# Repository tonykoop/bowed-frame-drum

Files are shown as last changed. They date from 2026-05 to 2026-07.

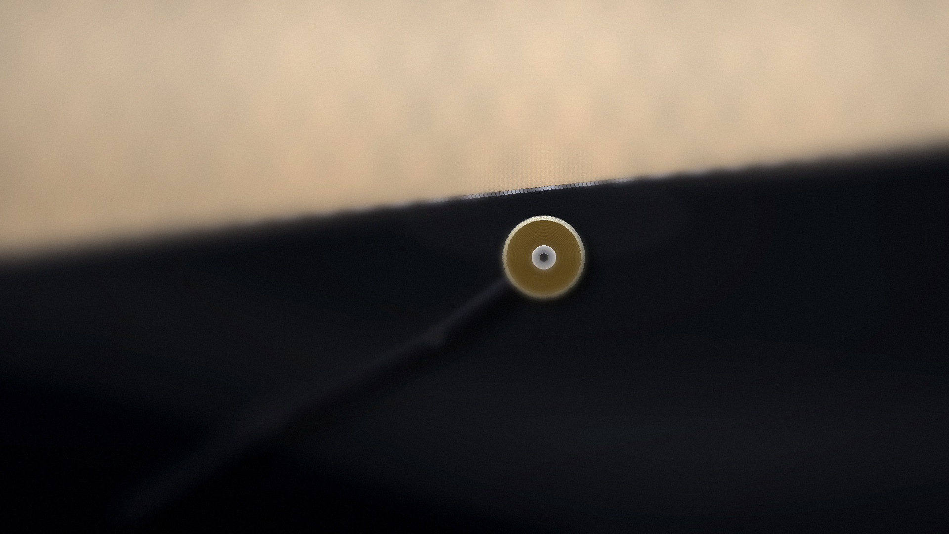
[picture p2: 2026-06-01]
images/macro/rosined-wheel-arm.png

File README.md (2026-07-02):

<!-- SPDX-License-Identifier: CC-BY-4.0 -->
# Bowed Frame Drum

Status: L2 V5 build-packet candidate - organized for prototype/shop review,
but not L3/build-ready. CAD/DXF outputs are planned placeholders, acoustic
targets are unmeasured predictions, and fabrication authority remains
`pending_measurement` until physical validation and reviewed CAD/DXF exist.

**Family**: Membranophone — frame drum  
**Archetype**: Irish bodhran  
**Target tuning**: C3 fundamental (130.8 Hz), A3 first overtone (219 Hz)  
**Ergonomic envelope**: 450 mm OD × 90 mm deep, ~900 g

## Design Thesis

A bodhran-scale frame drum with a rolled 1.0 mm cold-rolled steel cylinder frame instead of
the traditional laminated wood hoop. Inside the frame, a flat CR-steel tone bar (400 × 25 × 1 mm)
is suspended on two neoprene grommets and vibrates sympathetically when the head is struck,
adding an overtone shimmer near C4 (257 Hz). An optional rosined brass wheel on a cantilevered
arm produces a sustained bowed drone in the 80–400 Hz range — transforming a percussion instrument
into a hybrid membranophone/bowed instrument.

## Quick Stats

| | |
|---|---|
| Frame OD | 450 mm |
| Frame depth | 90 mm |
| Frame material | 1.0 mm CR steel, ASTM A1008, butt-TIG seam |
| Head | Remo Skyndeep 18" or goatskin, 430 mm playing OD |
| Tone bar | 400 × 25 × 1 mm CR flat bar, grommet-suspended |
| Tone bar pitch | ~257 Hz (C4 − 27¢), trim-tunable |
| Bowing | Optional: 50 mm brass rosined wheel on pivot arm |
| Est. build cost | ~$107 USD (materials + bought head) |

## Repository Structure

```
design.md               parametric design + geometry narrative
parameters.csv          all dimensions with units and confidence
bowed-frame-drum-starter.wl      acoustic model: Bessel membrane + Euler-Bernoulli bar modes
bom.csv                 full bill of materials
sourcing.csv            supplier SKUs and URLs
hardware.csv            fasteners and bought hardware
cut-list.csv            blank sizes and nesting notes
bend-table.csv          3 bends with allowance calculations
flat-pattern-checklist.md  DXF layers, naming, nesting
solidworks-plan.md      SolidWorks feature tree and global variables
fabrication-plan.md     14-step build sequence (Maker Nexus tools)
assembly-manual.md      final assembly steps + adjustment reference
validation.csv          target metrics with predicted values
tuning-notes.md         Bessel physics, screw-to-pitch mapping, bar trimming
risks.md                safety, manufacturability, acoustic, ergonomic risks
photo-shotlist.md       20 required shots for capstone deck
visual-bom-brief.md     brief for visual BOM illustration
visual-output-register.csv  V5 visual/CAD/DXF authority ledger
cad/mcp-session-log.md  V5 MCP/external-tool provenance stub
supplier-rfq.md         quote-ready RFQ text for sheet stock + head
explorer.html           interactive packet browser (Heifer Zephyr design language)
agent-record.md         session log: queries, assumptions, unknowns
wolfram/                bowed-frame-drum-wolfram-model.wl (source-only modal model)
drawings/               DXF flat patterns (stubs — populate with CAD)
cad/                    SolidWorks parts + assembly (stubs) + bowed-frame-drum.scad envelope master
evolution/              StudioPipeline Stage-0 intake (design intent, master manifest, revisions)
cnc/                    plasma/laser nesting plan (stubs)
learn-to-play/          bodhran technique stub
```

## License

- Hardware (CAD, DXF, BOM, fabrication plans): **CERN-OHL-W v2.0** — see LICENSE-HARDWARE.md
- Documentation (markdown, images): **CC BY 4.0** — see LICENSE-DOCS.md

---

*Round 5 Percussion — Lane 05 · Heifer Zephyr Instrument Series · v0.1.0-blueprint*

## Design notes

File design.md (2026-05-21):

<!-- SPDX-License-Identifier: CC-BY-4.0 -->
---
instrument: Bowed Frame Drum
family: membranophone
subfamily: frame-drum
origin_archetype: Irish bodhran
scale: chromatic sympathetic (tone bar tunable)
bore_profile: N/A (open frame cylinder)
target_fundamental_hz: 130
target_note: C3
tuning_mechanism: head-tension screws + tone-bar length trim
sheet_metal_challenge: rolled cylindrical frame + internal tone-bar suspension bracket
round: 5
lane: 05
version: v0.1.0-blueprint
date: 2026-05-21
---

# Bowed Frame Drum — Design Document

## Design Thesis

A bodhran-scale (~450 mm OD) frame drum with a rolled sheet-metal cylinder frame instead of
the traditional laminated wood hoop. Inside the frame a flat CR-steel tone bar is suspended
on two neoprene grommets; it vibrates sympathetically when the head is struck, adding an
overtone shimmer tuned to approximately C4 (260 Hz). An optional rosined-wheel assembly —
a 50 mm brass wheel on a cantilevered arm, rosined edge touching the head's inner rim —
produces a sustained bowed drone in the 80–400 Hz range when the arm is engaged.

The sheet-metal frame offers three advantages over wood: (1) dimensional precision from the
slip-roll, (2) weld-in grommet anchor points without splitting risk, (3) matte-black finish
gives a modern aesthetic while remaining acoustically transparent (the frame is a passive
radiator; head mass dominates).

## Geometry

```
Frame OD          : 450 mm
Frame ID          : 448 mm  (1 mm wall each side)
Frame depth       : 90 mm
Head playing OD   : 430 mm  (head slightly larger, clamped over rim)
Rim strip width   : 12 mm   (top + bottom, bent from 1 mm CR)
Tone bar          : 400 mm × 25 mm × 1 mm CR flat bar
Tone bar mount    : 2× brackets at 180° spacing, 50 mm from each end of bar
Grommet ID        : 5 mm  (bar thickness 1 mm; bar snaps into slot cut in grommet)
Rosined wheel OD  : 50 mm, brass, pivots on M5 stainless bolt
Rosined wheel arm : 60 mm × 15 mm × 1 mm CR, two 45° bends
```

## Acoustic Intent

| Mode | Target frequency | Note | Source |
|---|---|---|---|
| Head fundamental f₀₁ | ~130 Hz | C3 | Bessel J₀ first zero, tension tuned |
| Head overtone f₁₁ | ~220 Hz | A3 | Bessel mode 11; appears naturally |
| Tone bar bending mode 1 | ~260 Hz | C4 | Euler-Bernoulli free-free beam |
| Rosined wheel drone range | 80–400 Hz | — | Slip-stick excitation bandwidth |

The tone bar is intentionally detuned ~2 semitones above the head fundamental so sympathetic
ring decays slowly and adds air rather than masking. Trimming the bar shorter raises pitch;
adding blu-tack mass on the bar lowers pitch (field-adjustable).

## Sheet-Metal Authority Chain

### Frame ring
- Class: **cylinder**
- Material: 1.0 mm cold-rolled steel, ASTM A1008
- Blank: 1414.7 mm × 90 mm (π × 450 mm OD × depth)
- Seam: butt-TIG, full-penetration, fixture in V-block jig
- Spring-back: minimal on thin stock; overbend ~2° in slip-roll to compensate

### Rim reinforcement strips (×2)
- Class: **flat panel, rolled in-place**
- Blank: 1414.7 mm × 12 mm
- Operation: roll with frame; TIG-weld to top and bottom frame edges
- Provides: bearing surface for head wrap + stiffening ring against oval distortion

### Tone bar
- Class: **flat plate, no forming**
- Blank: 400 mm × 25 mm
- Operation: laser or plasma cut; edges deburred; no bends
- Suspend via 2× neoprene grommet mounts

### Tone bar mount brackets (×2)
- Class: **bracket, 1× 90° bend**
- Blank: 25 mm × 30 mm
- Bends: one 90° fold to form L; one leg rivets to frame ID wall, other leg cradles grommet

### Rosined wheel arm
- Class: **bracket, 2× bends**
- Blank: 80 mm × 15 mm
- Bends: 45° down at 20 mm from pivot end; 45° back at 50 mm (creates offset so wheel
  clears frame and contacts underside of head near rim)

## Seam Strategy

Butt + TIG throughout. Rationale: frame is structural (head tension ~60 N distributed),
butt-TIG is cleanest on 1.0 mm CR, lap joint would create inner ridge that snags head wrap.

## Tuning Mechanism

Head tension is set by 6× M4 × 30 mm cap-head screws threading into 6× M4 weld-nuts on the
frame OD, pulling a wrap-ring down over the head. Quarter-turn increments give ~8–12 Hz pitch
change at the fundamental. Tone bar pitch trimmed with angle grinder (shorten) or mass-loading.

## Ergonomics

Drum held in left arm, played with short tipper (traditional bodhran technique). Frame depth
90 mm provides grip without blocking playing hand. Rosined wheel arm on a spring-loaded pivot
— press with thumb to engage, release to disengage. Mass budget: frame ~700 g, head ~80 g,
hardware ~120 g, total ~900 g.

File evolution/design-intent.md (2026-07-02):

# Design Intent — bowed-frame-drum rev A

- Master CAD: `cad/bowed-frame-drum.scad` (sha256: 49b67e8979124685d6403cfb49bb805301c27a05e9e0b7eb080d7504441c73cc), envelope driven by `parameters.csv` (sha256: 0d1d12fdfadbcc3626e6cf1e9334d37dfee6ff22caee456e86e5b9a592aa85e0).
- Function: Bodhran-scale steel frame drum bowed with a rosined wheel — a rolled cold-rolled-steel frame ring carries a single goatskin/synthetic head under 6-screw tension, with an internal steel tone bar tuned to couple with the head, and a rosined brass wheel that continuously excites the head to sustain a bowed tone.
- Environment: hand-held/stand-mounted acoustic instrument; steel frame under moderate distributed head tension (~60 N over 6 screws); head tension + tone-bar coupling are the tuned load path; synthetic head option resists humidity.
- Target qty: 1 (prototype). Deadline: TBD. Budget/unit ceiling: TBD.

## Critical dimensions (carry tolerances)

| Feature | Nominal | Tolerance | Why critical | Source |
| --- | --- | --- | --- | --- |
| Frame OD | 450 mm | round-out on slip-roll | head seating / scale | parameters.csv frame_od (high) |
| Frame depth | 90 mm | cut-list gate | resonance / handling | parameters.csv frame_depth (high) |
| Head playing OD | 430 mm | frame_id − 18 mm wrap clearance | fundamental pitch scaling | parameters.csv head_playing_od (high) |
| Head target fundamental | 130 Hz (C3) | measured after tuning | acoustic intent | parameters.csv head_target_fundamental (high) |
| Tone bar length | 400 mm | trimming raises f_bar | head/bar coupling | parameters.csv tone_bar_length (high) |
| Tension screws | 6 × M4, 60° spacing | even star-pattern tension | uniform head tension | parameters.csv tension_screw_qty (high) |
| Rosined wheel OD | 50 mm | pivot / contact setup | bowed excitation | parameters.csv rosined_wheel_od (med) |

## Incidental (free for DFM)

- External finish, wheel-arm cosmetic form, mount/stand solution, non-mating surface treatment.

## Must-nots (DFM may never violate)

- Do not feed fingers past the slip-roll nip; stop the roll before removing the workpiece (risks.md safety).
- Do not run head tension to maximum to chase pitch — if pitch stays <100 Hz at max tension the head is too slack; use a thinner synthetic head instead (risks.md).
- Do not treat tone-bar length as final — modal coupling (17.4% delta) may require shortening ~20 mm to raise f_bar toward the head overtone (risks.md / tuning-notes.md).
- Do not treat the .scad head_thickness or rosined-wheel/pivot detail as fabrication dimensions — envelope + assumptions only.

## Material intent

- Preferred: cold-rolled steel (ASTM A1008) frame, rim strip, tone bar; goatskin or Remo Skyndeep head; brass rosined wheel; M4 tension hardware per bom.csv / hardware.csv.
- Acceptable subs: per sourcing.csv (spec-first; live prices unverified).
- Forbidden: none recorded.

## Stage status

Stage 0 intake complete 2026-07-01. Gate A (Alpha shop compile) NOT yet run — no concessions logged, nothing presented as shippable. Status preserved at L2 V5 build-packet candidate.

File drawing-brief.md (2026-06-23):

# Drawing Brief — Bowed Frame Drum

## Required Drawing Set

- Plan view: outside diameter, inside diameter (if applicable), head seat, and center.
- Cross-section: depth, wall thickness, and bearing-edge radius.
- Shell development / stave layout: miter angle, rough and final dimensions.
- Jig / fixture layout: clamp positions, stop blocks, forming diameter.
- Tensioning / tuning hardware detail: lug spacing, cord path, or rod positions.

## Datum Plan

- **Datum A** — drum center plane (axial reference).
- **Datum B** — bearing edge (front head seat).
- **Datum C** — stave seam or shell seam reference.

## Authority Note

All drawings are **first-prototype estimates** until a physical build validates
shell roundness, head fit, and tension response.  Promote a drawing from
`derived_preview` to `fabrication` authority only after measured dimensions
confirm the predicted geometry within acceptance tolerances.

## View Checklist

- [ ] Plan view (top-down, showing head area)
- [ ] Elevation / side view (full height with bearing edge)
- [ ] Cross-section (wall, bearing-edge radius, any internal profile)
- [ ] Stave / segment layout (if stave-built)
- [ ] Hardware detail (lugs, hooks, rods, or rope path)
- [ ] Jig / fixture drawing (if custom tooling required)

*See `visual-output-register.csv` for the authority status of each drawing file.*

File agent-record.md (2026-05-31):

<!-- SPDX-License-Identifier: CC-BY-4.0 -->
# Agent Record — Bowed Frame Drum

- **Runtime**: Claude Sonnet 4.6 (claude-sonnet-4-6) via FleetView Claude Code
- **Skills loaded**: sheet-metal, instrument-maker
- **Date**: 2026-05-21

## qmd Queries Run

| Query | Collection | Key findings |
|---|---|---|
| `qmd search "frame drum" -c instrument-builds` | instrument-builds | Found sprint triage docs noting `instrument-maker#83` (frame-drum) was closed; no prior build packet exists — this is a true greenfield |
| `qmd search "frame drum" -c instrument-wiki` | instrument-wiki | No frame drum wiki page exists; closest result was ceramic-hang membrane coupling patterns |
| `qmd vector_search "frame drum sheet metal membrane acoustic tuning"` | instrument-builds | No direct hits; confirms greenfield status |
| `qmd get /mnt/c/Users/Tony/Documents/GitHub/handpan/wolfram-starter.wl` | — | Used as Wolfram model template; adapted Bessel/plate model for membrane drum |
| `qmd get /mnt/c/Users/Tony/Documents/GitHub/handpan/design.md` | — | Used design.md frontmatter schema |

## Major Assumptions

1. **Head surface mass density**: assumed σ = 0.35 kg/m² for goatskin. Remo Skyndeep may be lighter (~0.25 kg/m²) — would raise predicted fundamental to ~155 Hz for same tension, meaning less screw torque needed to reach C3.

2. **Tone bar free-free BCs**: assumed both bar ends are truly free (unsupported). Grommet contact changes this slightly — actual mode 1 will be somewhat higher than 257 Hz depending on grommet stiffness. Treat 257 Hz as a lower bound; field trim to target.

3. **Head tension uniformity**: assumed uniform tension around circumference. Real bodhran heads with 6-screw tensioning have ±10–15% circumferential variation; actual fundamental may be ±10 Hz from prediction.

4. **Slip-roll spring-back**: 1.0 mm CR steel at 450 mm OD is a tight roll for most slip-rolls. Some machines need the third roll adjustment arm at maximum reach. Overbend 2° (target 358° arc) to compensate.

5. **Frame ID seam accessibility**: TIG welding the butt seam from the inside of a 448 mm ID × 90 mm deep cylinder is tight but feasible. A long reach TIG torch or inside-weld technique is required. Alternative: weld from outside only, but this means no internal flush grinding.

## Unknowns I'd Punt to Next Round

- **FEM validation** of head-bar sympathetic coupling: the Bessel + Euler-Bernoulli model gives first-order estimates only; FEM (ANSYS or Abaqus) would resolve whether the 17% coupling delta is sufficient for audible sympathetic ring.
- **Rosin formulation testing**: different rosins have very different slip-stick characteristics; recommend a 3-rosin comparison test (Hill, Pirastro Oliv, Hidersine) on the wheel.
- **Wheel arm spring design**: current design uses thumb-nut for tension adjustment. A leaf-spring detent (like a capo) would give cleaner engage/disengage; design deferred.
- **Bearing edge profile**: rim strip width (12 mm) and edge profile (sharp vs. 45° chamfer vs. round-over) affects head seating and sustain. Round-over of ~0.5 mm recommended but not detailed here.
- **CNC nesting plan**: `cnc/` directory stubbed. A full plasma nesting plan with lead-in/out and kerf compensation is needed before production.

## Files Produced

**Count**: 21 files across 6 directories

| File | Type |
|---|---|
| LICENSE | Combined license pointer |
| LICENSE-HARDWARE.md | CERN-OHL-W 2.0 |
| LICENSE-DOCS.md | CC BY 4.0 |
| README.md | Overview + repo map |
| design.md | Parametric design doc |
| parameters.csv | 47 parameters |
| bowed-frame-drum-starter.wl | Acoustic model (168 lines) |
| solidworks-plan.md | SW feature tree + global vars |
| flat-pattern-checklist.md | DXF naming, layers, nesting |
| bend-table.csv | 3 bends with allowances |
| cut-list.csv | 6 blank entries |
| fabrication-plan.md | 38-step build sequence |
| assembly-manual.md | Assembly + adjustment guide |
| bom.csv | 23 line items |
| sourcing.csv | 13 supplier entries |
| hardware.csv | 11 fastener/hardware entries |
| supplier-rfq.md | 3 RFQ blocks |
| validation.csv | 13 metrics with predictions |
| risks.md | Safety + mfg + acoustic + ergonomic |
| tuning-notes.md | Bessel physics + trim tables |
| photo-shotlist.md | 20 required shots |
| visual-bom-brief.md | BOM render brief |
| explorer.html | Interactive packet browser |
| agent-record.md | This file |
| learn-to-play/fingerings/basic-strokes.md | Bodhran technique stub |
| drawings/.gitkeep | DXF placeholder |
| cad/.gitkeep | CAD placeholder |

## Coupon Tests Recommended

1. Slip-roll spring-back coupon (200 × 90 mm strip) — critical before rolling frame
2. TIG butt-weld coupon (150 mm) — bend to fracture to verify fusion
3. Grommet press-fit coupon — verify 14 mm OD grommet fit in 13.8 mm hole without splitting

## Confidence

| Area | Confidence | Notes |
|---|---|---|
| Acoustic targets | Medium | Bessel mode estimates ±10%; goatskin σ assumption unverified |
| Flat patterns | High | Frame ring geometry is elementary cylinder; tone bar/brackets trivial |
| Fabrication plan | High | All operations are standard Maker Nexus tooling; no exotic forming |
| BOM | High | All parts are commodity hardware; prices are current estimates |
| Sympathetic coupling | Low-Medium | 17% delta is borderline; needs physical test |
| Bowing mode | Medium | Slip-stick physics well understood; rosin formulation needs test |

## Suggested Next-Round Task

1. **Physical prototype**: build the frame ring (slip-roll + TIG); validate roundness.
2. **Tone bar acoustic test**: clamp tone bar in two grommets, strike with mallet, measure fundamental.
3. **CAD modeling**: build SolidWorks parametric assembly per `solidworks-plan.md`.
4. **Wiki page**: create `instrument-wiki/instruments/bowed-frame-drum.md` after prototype results.
5. **Learn-to-play expansion**: record audio examples of basic strokes + bowing mode.

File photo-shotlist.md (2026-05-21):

<!-- SPDX-License-Identifier: CC-BY-4.0 -->
# Photo Shot List — Bowed Frame Drum

## Required Photos (Capstone Deck)

| # | Shot description | Stage | Notes |
|---|---|---|---|
| 01 | Frame ring blank laid flat on workbench | Pre-roll | Show dimensions, shear marks |
| 02 | Slip-roll in action, blank feeding | Rolling | Side angle showing cylinder forming |
| 03 | Frame cylinder on V-block, tack-weld stage | Welding | Show clamp and tack positions |
| 04 | TIG welder running frame seam | Welding | Action shot; eye protection required |
| 05 | Seam after flap-disc flush | Post-weld | Close-up showing weld quality |
| 06 | Frame roundness check with calipers | QC | Show caliper at 4 positions |
| 07 | Rim strips seated and tack-welded | Rim assembly | Show top edge with strips |
| 08 | All 6 M4 tension holes drilled | Drilling | Show drill press setup |
| 09 | Tone bar with grommets installed | Sub-assembly | Close-up of grommet isolation |
| 10 | Tone bar mounted inside frame | Assembly | Frame interior view; bar visible |
| 11 | Rosined wheel arm detail | Detail | Wheel, pivot, arm offset geometry |
| 12 | Head installation — stretching stage | Head install | Show hand-pull even tension technique |
| 13 | Tension ring seated with screws | Head install | Show star-pattern tightening |
| 14 | Finished drum, front face (head) | Complete | Clean studio shot on white background |
| 15 | Finished drum, profile view | Complete | Show 90mm depth, frame edge detail |
| 16 | Finished drum, interior detail | Complete | Mirror/phone view of tone bar inside |
| 17 | Tuner app showing C3 fundamental | Validation | Phone screen + drum in frame |
| 18 | Player holding drum in bodhran position | Playability | Left arm cradle, tipper in right |
| 19 | Rosined wheel engaged — bowing demo | Playability | Show wheel contact with head |
| 20 | Macro: butt-weld seam cross-section (coupon) | QC documentation | Cut and etch coupon to show fusion |

## Optional / Nice-to-Have

- Time-lapse of full fabrication sequence
- Oscilloscope or FFT capture showing head fundamental + tone bar sympathetic ring
- Before/after: frame ring blank → finished drum overlay

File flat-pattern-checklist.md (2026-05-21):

<!-- SPDX-License-Identifier: CC-BY-4.0 -->
# Flat-Pattern Checklist — Bowed Frame Drum

## DXF Naming Convention

```
bfd-<part>-flat-v<rev>.dxf
Examples:
  bfd-frame-ring-flat-v1.dxf
  bfd-tone-bar-flat-v1.dxf
  bfd-mount-bracket-flat-v1.dxf
  bfd-wheel-arm-flat-v1.dxf
```

## Units

All DXFs in **millimeters**. Declare `$INSUNITS = 4` (mm) in DXF header.

## Layer Scheme

| Layer name | Color | Content |
|---|---|---|
| `CUT` | Red (1) | Outer profile for plasma/laser cut path |
| `BENDS` | Yellow (2) | Bend center-lines (not cut) |
| `ETCH` | Cyan (4) | Reference marks, text labels |
| `HOLES` | Magenta (6) | Interior hole profiles |
| `DIMS` | White (7) | Dimension annotation (PDF export only) |

## Tab-and-Slot Strategy

Frame ring and tone bar have no tabs. Mount brackets use a single punched slot
(6 mm × 12 mm) in the long leg for rivet alignment. No interlocking tabs needed
because all structural joints are welded or riveted after forming.

## Part-by-Part Checklist

### Frame Ring Flat (bfd-frame-ring-flat-v1.dxf)
- [ ] Outer rectangle: 1414.7 mm × 90.0 mm on `CUT` layer
- [ ] 6× M4 tension holes (ø4.5 mm) at x = {78.5, 314.0, 549.5, 785.0, 1020.5, 1256.0} mm, y = 45.0 mm on `HOLES` layer
- [ ] Seam alignment etch marks at x = 0 and x = 1414.7 mm on `ETCH` layer
- [ ] Spring-back compensation note: overbend to ~178° in slip-roll

### Tone Bar Flat (bfd-tone-bar-flat-v1.dxf)
- [ ] Outer rectangle: 400.0 mm × 25.0 mm on `CUT` layer
- [ ] 2× grommet holes (ø6 mm) at x = {50, 350} mm, y = 12.5 mm on `HOLES` layer
- [ ] Centerline etch at y = 12.5 mm on `ETCH` layer

### Mount Bracket Flat (bfd-mount-bracket-flat-v1.dxf)
- [ ] Outer rectangle: 25.0 mm × 30.0 mm on `CUT` layer
- [ ] Bend line at y = 15.0 mm on `BENDS` layer
- [ ] 1× grommet boss hole (ø6 mm) at x = 12.5 mm, y = 22.5 mm (short leg center) on `HOLES` layer
- [ ] 2× rivet holes (ø3.3 mm for M3 rivet) at x = {7, 18} mm, y = 7.5 mm (long leg) on `HOLES` layer
- [ ] Bend direction arrow on `ETCH` layer

### Wheel Arm Flat (bfd-wheel-arm-flat-v1.dxf)
- [ ] Outer rectangle: 80.0 mm × 15.0 mm on `CUT` layer
- [ ] Bend line 1 at x = 19.5 mm (accounting for bend allowance for 45°) on `BENDS` layer
- [ ] Bend line 2 at x = 49.3 mm (after first bend allowance) on `BENDS` layer
- [ ] M5 pivot hole (ø5.5 mm) at x = 75 mm, y = 7.5 mm on `HOLES` layer
- [ ] Bend direction arrows on `ETCH` layer

## Bend Allowance Reference

Formula: BA = (π/180) × angle × (inside_radius + k × thickness)

| Part | Angle | Inside R (mm) | K | Thickness (mm) | BA (mm) |
|---|---|---|---|---|---|
| Mount bracket | 90° | 1.5 | 0.44 | 1.0 | 3.21 |
| Wheel arm bend 1 | 45° | 1.5 | 0.44 | 1.0 | 1.60 |
| Wheel arm bend 2 | 45° | 1.5 | 0.44 | 1.0 | 1.60 |

Frame ring and tone bar: no closed-form bends (rolled or flat).

## Nesting Notes

Plasma nest all 1.0 mm CR parts on a single 1500 mm × 500 mm sheet:
- Frame ring blank is the largest part and sets sheet height (90 mm → fits in 500 mm width)
- Nest frame ring first (1414.7 × 90 mm) with 5 mm edge margin
- Nest 2× mount brackets and 1× wheel arm and 1× tone bar in remaining space
- Lead-in: 5 mm external lead-in on all outer profiles

## Coupon Tests Required

1. **Slip-roll spring-back coupon**: Roll a 200 mm × 90 mm strip of the same 1.0 mm CR stock,
   measure actual OD vs target, adjust roll gap before running full frame blank.
2. **TIG butt-weld coupon**: Weld a 150 mm test strip butt joint, bend to fracture — confirm
   full fusion before welding frame seam.

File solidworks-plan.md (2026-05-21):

<!-- SPDX-License-Identifier: CC-BY-4.0 -->
# SolidWorks Plan — Bowed Frame Drum

## Global Variables / Equations

Define all dimensions as global variables so the assembly parametrically updates:

```
"FrameOD"        = 450    mm
"FrameDepth"     = 90     mm
"WallThick"      = 1.0    mm
"FrameID"        = "FrameOD" - 2 * "WallThick"
"HeadPlayingOD"  = 430    mm
"RimStripW"      = 12     mm
"ToneBarL"       = 400    mm
"ToneBarW"       = 25     mm
"ToneBarH"       = 1.0    mm
"GrommetID"      = 6      mm
"WheelOD"        = 50     mm
"WheelW"         = 8      mm
```

## Feature Tree — Frame Ring Part (frame-ring.sldprt)

1. Sketch 1 (top plane): rectangle representing blank profile (1414.7 mm × 90 mm)
2. Sheet Metal: set thickness = WallThick, K-factor = 0.44, bend radius = 1.5 mm
3. Base Flange: extrude 90 mm (the frame height direction)
4. Rolled Bead: wrap the flat blank into a cylinder (SolidWorks Sheet Metal rolled bead)
   — this is done by inserting a rolled seam reference in the flat pattern
5. Flat Pattern: auto-generated; confirm OD = π × 450 = 1414.7 mm ± 0.5 mm
6. Cut-Extrude: 6× M4 tension holes, ø4.5 mm through, at 60° spacing on frame OD,
   centered at mid-depth (45 mm from each edge)
7. Weld-Nut bosses: note in drawing (not modeled — added at fab)
8. Mate reference: centerline axis for assembly placement

## Feature Tree — Tone Bar Part (tone-bar.sldprt)

1. Sheet Metal base: 400 mm × 25 mm × 1 mm flat plate
2. No bends — flat part
3. Cut-Extrude: 2× ø6 mm grommet slot holes, centered at 50 mm from each end
4. Flat Pattern: identical to blank (no bend development needed)

## Feature Tree — Tone Bar Mount Bracket (tone-bar-mount.sldprt)

1. Sheet Metal base: 30 mm × 25 mm blank
2. Edge Flange: 90° bend at 15 mm from one end → L-bracket
   - Long leg (15 mm): rivets to frame ID wall
   - Short leg (15 mm): has ø6 mm boss for grommet
3. Flat Pattern: 30 mm × 25 mm before bend

## Feature Tree — Rosined Wheel Arm (wheel-arm.sldprt)

1. Sheet Metal base: 80 mm × 15 mm blank
2. Edge Flange 1: 45° bend at 20 mm → offsets wheel toward head underside
3. Edge Flange 2: 45° return at 50 mm → returns arm parallel to frame for pivot mount
4. Cut: ø5.5 mm pivot hole at tail end (M5 clearance)
5. Flat Pattern: 80 mm × 15 mm (sum of developed arc sections)

## Feature Tree — Master Assembly (bowed-frame-drum.sldasm)

1. Insert frame-ring (fixed at origin)
2. Insert 2× tone-bar-mount brackets at 180° positions, 45 mm depth, riveted to frame ID
3. Insert tone-bar, dropped through grommet holes in mounts
4. Insert 2× neoprene grommets (bought component, simplified model)
5. Insert wheel-arm at 12 o'clock position, M5 pivot bolt through frame top edge
6. Insert brass wheel on pivot
7. Mates: coincident, parallel, concentric as required

## Configurations

| Config | Description |
|---|---|
| Default | Standard assembly with wheel arm parked (disengaged) |
| Bowing | Wheel arm engaged, wheel contacts head underside at 5 mm inset |
| Flat patterns | Drive-by flat-pattern config for all sheet-metal parts |

## Drawings

- `drawings/frame-ring-flat.dxf` — frame blank flat pattern (plasma/laser cut)
- `drawings/frame-ring-fabrication.pdf` — dimensioned fab drawing
- `drawings/tone-bar-flat.dxf` — tone bar flat + grommet holes
- `drawings/mount-bracket-flat.dxf` — bracket flat + bend line
- `drawings/wheel-arm-flat.dxf` — wheel arm flat + two bend lines
- `drawings/assembly-overview.pdf` — exploded view with callouts

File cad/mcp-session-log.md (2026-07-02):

# Bowed Frame Drum MCP Session Log

Status: provenance stub only. No MCP, CAD, drawing, render, Photoshop,
Illustrator, Blender, OpenSCAD, Wolfram runtime, or physical measurement
session was run in this V5 migration lane.

This file exists so future V5 work can record external-tool provenance before
promoting any CAD, DXF, render, visual BOM, print plate, or model output. The
current packet is an L2 review surface: planned geometry and acoustic targets
are grounded in existing repo files, but they remain `pending_measurement`.

## qmd Step 0

| command | result | authority impact |
| --- | --- | --- |
| `qmd search "bowed-frame-drum" -c instrument-builds` | No results found. | No prior qmd packet was used as authority. |
| `qmd query "bowed frame drum V5 build packet"` | Crashed in the local Bun/node-llama path under timeout. | Query result was not used as authority; existing repo files are the evidence source. |

## Session Register

| session_id | tool | input_authority | outputs | role | authority_result | review_status | notes |
| --- | --- | --- | --- | --- | --- | --- | --- |
| none-2026-05-29-r3 | none | `README.md`; `design.md`; `parameters.csv`; `validation.csv`; `solidworks-plan.md`; `flat-pattern-checklist.md` | `visual-output-register.csv`; `cad/mcp-session-log.md`; README status line | V5 migration scaffold | pending_measurement | self_checked | Local-only migration. No geometry, coordinates, tuning measurements, or renders were created. |
| TBD | SolidWorks or CAD MCP | `PARAM-001`; `SWPLAN-001` | planned native CAD files under `cad/` | cad_authoring | pending_measurement | unreviewed | Future session must trace dimensions to `parameters.csv` and record review status before any CAD authority claim. |
| TBD | Illustrator/Fusion/DXF tool | `DXFPLAN-001`; future reviewed CAD | planned DXF/SVG/PDF drawings under `drawings/` | drawing_cleanup | pending_measurement | unreviewed | Future session must export real flat patterns, preserve millimeter units, and pass a DXF review before fabrication use. |
| TBD | Blender/image tool | future reviewed CAD or build photos | planned visual BOM/render assets | concept_render | concept_only | unreviewed | Future visual assets are communication only unless each callout cites a controlling authority row. |
| TBD | Wolfram runtime | `WOLFRAM-001`; `validation.csv` | executed plots/tables if generated | computational_model | pending_measurement | unreviewed | Source exists, but no runtime execution log or measurement comparison is committed. |
| fable-v5-refresh-2026-07-01 | claude-code (Fable 5) + OpenSCAD CLI | `parameters.csv`; `design.md` | `cad/bowed-frame-drum.scad` | cad_authoring | pending_measurement | self_checked | Parametric frame-drum envelope master (frame OD 450 mm, depth 90 mm, head OD 430 mm, 6xM4 tension field, 400 mm tone bar on 2 brackets, 50 mm rosined wheel) — all from parameters.csv. Tuning-sensitive tone-bar modal tuning + wheel contact + head tension out of scope. openscad render check: pass (Simple: yes, exit 0). NOT fabrication authority until reviewed. |

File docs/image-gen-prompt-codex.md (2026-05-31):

# Bowed Frame Drum Image-Gen Prompts

Concept visualization only; not fabrication authority. Do not infer final
bracket geometry, wheel contact force, tone-bar dimensions, or tuning from
these prompts.

## Hero Prompt

Photorealistic 3/4 product photograph of a bowed frame drum concept: a bodhran-scale single-head frame drum with a matte black rolled sheet-metal cylinder frame, a natural or synthetic head, visible tension screws around the rim, and an internal flat steel tone bar suspended on small neoprene grommets. Include the optional rosined brass wheel assembly on a small pivoting arm near the inner rim, clearly presented as a real mechanism that can touch the head for sustained bowed drone. Clean studio background, a short tipper and small rosin block nearby for scale, soft directional lighting, 50mm lens, high detail, photorealistic.

## In-Context Prompt

Photorealistic performance-workshop scene of the bowed frame drum held like a bodhran, one hand supporting the frame while the other plays with a short tipper and the thumb engages a small rosined brass wheel near the rim. Show the internal tone bar subtly through the open back, a modern metal-shop aesthetic, and a tuner or adjustment tools on a nearby bench. Natural light, believable hand posture, restrained experimental-instrument mood.

## Detail / Macro Prompt

Photorealistic macro close-up of the bowed frame drum's signature hybrid mechanism: a small brass rosined wheel on a bent steel pivot arm touching the underside edge of the drumhead, with a flat steel tone bar and neoprene grommet mount visible behind it. Emphasize real fasteners, matte black frame finish, brass edge texture, and head surface grain. High-detail macro, shallow depth of field.

## Negative / Avoid

No text, logos, watermarks, violin bow, impossible wheel contact, extra fingers, distorted hands, fake labels, or fantasy electronics.

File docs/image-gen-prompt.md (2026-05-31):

<!-- SPDX-License-Identifier: CC-BY-4.0 -->
# Image-Gen Prompts

Concept image only; not fabrication authority. Do not include cut-ready dimensions, hole locations, or toolpaths.

## Hero Prompt

A finished hybrid bowed frame drum, bodhran-scale and roughly the size of a large pizza held in one arm, photographed as a real physical object. The defining silhouette is a shallow rolled-steel cylinder frame — a single clean welded steel hoop in a matte-black powder-finish, with a thin reinforcing rim strip running around the top and bottom edges. A tan goatskin-style synthetic drum head is stretched taut across the front face and clamped over the rim by a slim silver tension wrap-ring secured with a star pattern of small cap-head screws around the circumference. Through the open back you can glimpse a thin flat steel tone bar suspended across the interior on two small dark neoprene grommets. Mounted at the inner rim, the signature feature: a small rosined brass wheel (warm gold tone) on a slender double-bent steel pivot arm, positioned so its rosined edge can touch the underside of the head to bow a sustained drone. Materials read honestly — brushed and blackened cold-rolled steel, warm brass, taut hide-toned membrane. Clean neutral light-gray studio background, soft directional studio light, three-quarter product-photography angle, ~50mm lens, high detail, photorealistic, no text labels.

## In-Context Prompt

The bowed frame drum staged in a metal-fabrication workshop, resting on a worn wood-top workbench beside a slip-roll and a TIG torch coiled in the soft background. Warm natural window light rakes across the matte-black steel frame and catches the gold of the rosined brass wheel and the taut tan head. A player's left arm begins to cradle the drum in traditional bodhran hold with a short wooden tipper resting nearby. Shallow depth of field, environmental storytelling of a shop-built hybrid percussion instrument, concept visualization only, photorealistic, no text labels.

## Detail Prompt

Macro close-up of the rosined brass wheel assembly at the inner rim of the frame drum: a small gold-toned brass wheel mounted on a stainless pivot bolt at the end of a slender double-bent blackened-steel arm, its rosined contact edge poised against the underside of the taut tan drum head near the rim. In the soft background, the thin flat steel tone bar floats on its dark neoprene grommet, isolated from the frame. Raking side light reveals brushed-metal texture, the dull sheen of rosin on brass, the weave and grain of the head membrane, and the crisp welded edge of the rim strip. High detail, shallow focus, photorealistic, no measurements.

## Negative / Avoid

No text, logos, watermarks, or fake maker marks; no dimension callouts or measurement lines; no impossible mechanisms; brass wheel and pivot arm must look load-bearing and plausible; anatomically plausible hands if a player is shown.

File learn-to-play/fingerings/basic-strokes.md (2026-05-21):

<!-- SPDX-License-Identifier: CC-BY-4.0 -->
# Bowed Frame Drum — Basic Strokes & Technique

## Holding Position (Traditional Bodhran)

1. **Left arm cradle**: Grip the frame with your left hand, thumb on the outside (at 9 o'clock),
   fingers through the inside of the frame. Rest the drum against your forearm.
2. **Left hand damping**: Your left hand inside the drum controls resonance — press fingers
   against the underside of the head to damp overtones and pitch-shift the fundamental.
3. **Right hand tipper**: Hold the tipper (a short double-headed beater, ~20 cm) between thumb
   and index finger, rotating the wrist for stroke and return.

## Core Strokes (Tipper)

| Stroke | Description | Sound |
|---|---|---|
| **Tip** | Tipper tip hits center of head | Full resonant bass tone |
| **Heel** | Heel (back end) of tipper hits center | Shorter, drier accent |
| **Mute-tip** | Left hand fully damped; tip strike | Dry "thock" with no sustain |
| **Rim shot** | Tip strikes both head and rim simultaneously | Sharp crack accent |
| **Roll** | Rapid alternating tip/heel | Sustained tremolo effect |

## Tone Bar Sympathetic Shimmer

After each tip stroke, the internal tone bar (if properly tuned) adds a ~0.5–1 second
sympathetic shimmer ring. To maximize it:
- Strike firmly near head center
- Release left-hand damping after the initial attack
- Let head ring freely — shimmer builds as head oscillates

To suppress shimmer: maintain left-hand contact on head underside throughout stroke.

## Bowing Mode (Rosined Wheel)

Engage the wheel arm by pressing inward with left thumb until wheel contacts head inner rim.

**Basic bowing**:
1. Engage wheel arm
2. Apply light consistent pressure (50–100 g)
3. Rotate the drum or move the arm at 0.2–0.5 m/s
4. Allow 1–2 seconds for drone to build
5. Vary left-hand damping to shape the drone pitch (more pressure = higher pitch range)

**Drone + percussion combination**:
1. Engage drone with left thumb
2. Strike head with right-hand tipper simultaneously
3. Drone sustains under percussive attack for a hybrid drone-drum texture

## Tuning Guide (Quick Reference)

- Too low: tighten tension screws 1/4 turn each in star pattern (1-4-2-5-3-6)
- Too high: loosen 1/4 turn each
- Target fundamental: **C3 (130.8 Hz)**
- Use a chromatic tuner app — strike center of head

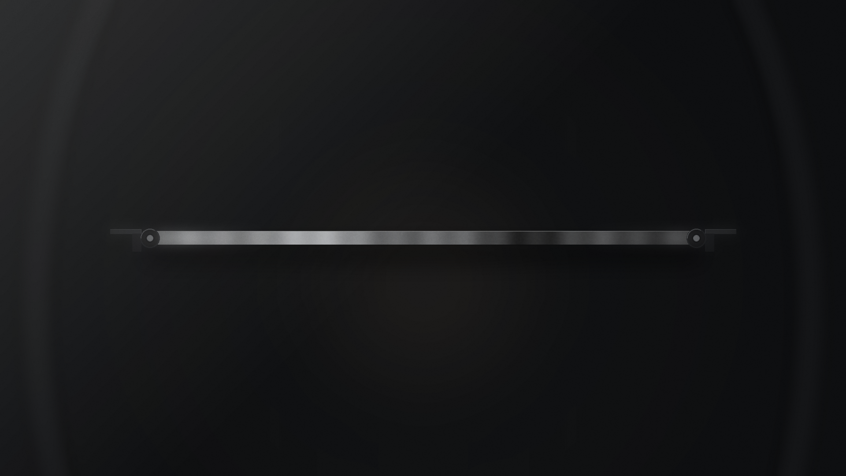
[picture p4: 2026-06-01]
images/macro/suspended-tone-bar.png

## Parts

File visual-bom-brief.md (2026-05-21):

<!-- SPDX-License-Identifier: CC-BY-4.0 -->
# Visual BOM Brief — Bowed Frame Drum

## Brief for Visual BOM Render

The visual BOM for the Bowed Frame Drum should show an exploded-view illustration
of the six major subassembly groups, arranged from left to right in build sequence:

**Group 1 — Frame Ring** (center of composition): the rolled steel cylinder
(450 mm OD × 90 mm deep), with rim strips on top and bottom edges shown in
contrasting color. Six M4 tension-screw holes visible on the outer surface.

**Group 2 — Tone Bar Suspension**: two L-bracket mounts floating above/below the
frame cylinder center, with tone bar (thin flat bar, 400 mm) running between them
on neoprene grommets (shown as dark rubber rings).

**Group 3 — Rosined Wheel Assembly**: shown to the upper-right of the frame —
the double-bent arm, brass wheel (gold color), and M5 pivot hardware.

**Group 4 — Head + Tension Ring**: above the frame — goatskin or synthetic drum head
(tan/cream), with the tension wrap-ring (silver annulus) and six M4 cap screws
arranged in a star pattern.

**Group 5 — Hardware Callouts**: small bubble callouts for grommets, rivets, bolts,
jam nuts — with item numbers keying to bom.csv.

**Group 6 — Finish Note**: a palette swatch showing matte black rattle-can option
vs. natural steel option.

## Style

Use Heifer Zephyr palette: walnut (#3D2817), cedar (#B98B47), cream (#F8F4E9),
lapis (#1E3A8A). Steel parts in mid-gray. Brass wheel in cedar/gold tone.
Line-art exploded view preferred over photorealistic render for this blueprint round.

## Target Use

Capstone deck slide 3, instrument-showcase library card background, and explorer.html
image section.

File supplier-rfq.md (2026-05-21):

<!-- SPDX-License-Identifier: CC-BY-4.0 -->
# Supplier RFQ — Bowed Frame Drum

## Sheet Stock RFQ (Online Metals or equivalent)

> **Request for Quote**
>
> Material: Cold-rolled steel sheet, ASTM A1008 / SAE 1008/1010
> Thickness: 1.0 mm (0.040") / 20 gauge
> Size: 1500 mm × 500 mm (59.1" × 19.7") — one sheet
> Finish: Mill finish, oiled (standard CR)
> Quantity: 1 sheet (prototype run)
>
> Notes: All dimensions will be plasma or laser cut to net shape in-house.
> No edge treatment required. Certify ASTM A1008 with MTR if possible.
>
> Please quote with shipping to [ZIP code].

Estimated cost: $22–$35 USD delivered.

## Drum Head RFQ (Remo or distributor)

> **Request for Quote**
>
> Product: Remo Skyndeep 18" Frame Drum Head
> Model: FD-0018-71 (or equivalent 18-inch / 457 mm synthetic frame drum head)
> Quantity: 1
>
> Notes: Synthetic preferred (humidity stable). Goatskin acceptable if Skyndeep unavailable.
> Ship to [ZIP code].

Estimated cost: $20–$28 USD.

## Laser Cutting Sub (if no in-house plasma)

> **Request for Quote — Laser Cutting**
>
> Material: 1.0 mm CR steel (customer-supplied or cut from 1500×500 sheet)
> Parts:
>   - 1× Tone bar: 400 × 25 mm, 2× ø6mm holes
>   - 2× Mount bracket: 30 × 25 mm, 1× ø6mm + 2× ø3.3mm holes each
>   - 1× Wheel arm: 80 × 15 mm, 1× ø5.5mm hole
>   - Note: frame ring (1414.7 × 90 mm) to be slip-rolled in-house — not in this quote
>
> DXF files available on request. Units: mm, layers per ANSI Y14.26M.
> Quantity: prototype (×1 each part)
>
> Please quote laser cut + deburr (no forming — forming in-house).

Estimated cost: $40–$80 USD for small-part laser cutting.

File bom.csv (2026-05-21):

# SPDX-License-Identifier: CERN-OHL-W-2.0
part | qty | material | thickness_gauge | supplier | cost_usd | lead_time_days | notes
CR steel sheet 1500x500mm | 1 | ASTM A1008 cold-rolled steel | 1.0mm / 20ga | Online Metals | 22.00 | 3 | yields frame + rim strips + tone bar + brackets + wheel arm
Frame ring blank cut | 1 | CR steel | 1.0mm | — | 0 | 0 | from sheet above; 1414.7 x 90mm
Rim strip top | 1 | CR steel | 1.0mm | — | 0 | 0 | 1414.7 x 12mm; from same sheet
Rim strip bottom | 1 | CR steel | 1.0mm | — | 0 | 0 | 1414.7 x 12mm; from same sheet
Tone bar | 1 | CR steel | 1.0mm | — | 0 | 0 | 400 x 25mm flat; laser cut
Mount bracket | 2 | CR steel | 1.0mm | — | 0 | 0 | 30 x 25mm; laser cut + brake bent
Wheel arm | 1 | CR steel | 1.0mm | — | 0 | 0 | 80 x 15mm; laser cut + 2x brake bends
Brass wheel 50mm OD | 1 | brass | 8mm wide | McMaster-Carr 8972K61 or equiv | 14.50 | 2 | rosined bowing wheel; optional
ER70S-6 TIG filler 1/16" | 0.5 | kg | steel TIG wire | Airgas / Miller | 8.00 | 1 | frame seam + rim strip welds
M4 x 30mm cap screw | 6 | steel zinc-plated |  | McMaster-Carr | 0.90 | 2 | head tension screws
M4 weld nut | 6 | steel |  | McMaster-Carr | 1.20 | 2 | weld to frame OD
M3 x 6mm blind rivet | 4 | aluminum |  | Home Depot | 0.80 | 1 | bracket rivets; 2 per bracket
M3 x 20mm cap screw | 2 | steel |  | McMaster-Carr | 0.60 | 2 | tone bar end retention
M3 hex nut jam | 2 | steel |  | McMaster-Carr | 0.30 | 1 | tone bar jam nut
M5 x 30mm bolt | 1 | stainless |  | McMaster-Carr | 0.80 | 2 | wheel arm pivot
M5 thumb nut | 1 | steel |  | McMaster-Carr | 1.20 | 2 | wheel arm tension adj
M5 x 12mm bolt | 1 | stainless |  | McMaster-Carr | 0.60 | 2 | brass wheel pivot
PTFE washer M5 | 4 | PTFE |  | McMaster-Carr | 1.40 | 2 | wheel pivot friction reduction
Neoprene grommet 14mm OD 6mm ID | 2 | neoprene |  | McMaster-Carr 9325K15 or equiv | 2.60 | 2 | tone bar suspension; vibration isolation
Drum head 18in | 1 | Remo Skyndeep or goatskin |  | Guitar Center / Remo | 24.00 | 1 | 460mm OD; 18in standard frame drum head
Tension wrap-ring 430mm OD | 1 | aluminum 1.5mm | 1.5mm | fabricated from 1.0mm scrap or bought hoop ring | 5.00 | 3 | press over head to lock; 12mm wide
Cake rosin | 1 | violin rosin |  | Amazon / music store | 8.00 | 2 | for rosined bowing wheel
Matte black spray paint | 1 | Rust-Oleum 2x | — | Home Depot | 8.00 | 1 | finish coat; optional
Self-etching primer spray | 1 | Rust-Oleum | — | Home Depot | 7.00 | 1 | adhesion under topcoat; optional

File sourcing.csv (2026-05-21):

# SPDX-License-Identifier: CERN-OHL-W-2.0
supplier | part | sku | url | min_qty | notes
Online Metals | 1.0mm CR steel sheet ASTM A1008 |  | https://www.onlinemetals.com | 1 sheet | choose 1500x500 or larger; specify 20ga CR
McMaster-Carr | M4 x 30mm cap screw 18-8 SS | 92196A102 | https://www.mcmaster.com | 25 pack | stainless preferred for rust resistance
McMaster-Carr | M4 weld nut standard | 90594A009 | https://www.mcmaster.com | 10 pack | weld to frame exterior
McMaster-Carr | M3 blind rivet aluminum | 97259A115 | https://www.mcmaster.com | 50 pack | bracket to frame rivets
McMaster-Carr | M5 stainless bolt 30mm | 91287A198 | https://www.mcmaster.com | 10 pack | wheel arm pivot
McMaster-Carr | Neoprene grommet 14mm OD 6mm ID | 9325K15 | https://www.mcmaster.com | 10 pack | tone bar suspension
McMaster-Carr | PTFE washer M5 | 98025A031 | https://www.mcmaster.com | 25 pack | wheel pivot friction
Remo | Skyndeep 18in frame drum head |  | https://www.remo.com | 1 | model FD-0018-71 or equivalent; weatherproof synthetic
Guitar Center | Remo 18in head alternate |  | https://www.guitarcenter.com | 1 | if Remo direct out of stock
Amazon | Violin cake rosin |  | https://www.amazon.com | 1 block | any standard violin rosin brand; Pirastro or Hill preferred
Home Depot | Rust-Oleum matte black 2X spray |  | https://www.homedepot.com | 1 can | item 267736
Home Depot | Rust-Oleum self-etching primer |  | https://www.homedepot.com | 1 can | item 249322
Airgas / Miller | ER70S-6 TIG wire 1/16 |  | https://www.airgas.com | 0.5 kg spool | standard mild steel TIG filler

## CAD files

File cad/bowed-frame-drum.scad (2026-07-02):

// bowed-frame-drum.scad — parametric frame + tone-bar + wheel envelope master
// =====================================================================
// SOURCE OF TRUTH: parameters.csv (design-intent parameter table) + design.md.
// AUTHORITY: pending_measurement. HONEST ENVELOPE SCAFFOLD, NOT fabrication
//   authority until reviewed against SolidWorks masters (solidworks-plan.md) or
//   measured prototype evidence.
//
// SCOPE / BOUNDARY (per V5 percussion addendum):
//   - Models the rolled steel FRAME ring + head disc + rim strip + tension-screw
//     field + internal tone bar (on its two mount brackets) + rosined-wheel
//     envelope, so overall geometry traces to parameters.csv.
//   - TUNING-SENSITIVE geometry is OUT OF SCOPE: exact tone-bar modal tuning,
//     rosined-wheel contact/pivot mechanism detail, and the head tension field
//     are hand-refined regions and are NOT modeled as fabrication solids.
//
// Render check: openscad -o /tmp/bowed-frame-drum-check.stl this-file (exit 0)
// =====================================================================

/* [Frame — parameters.csv] */
frame_od_mm        = 450;   // parameters.csv frame_od (bodhran scale)
wall_thickness_mm  = 1.0;   // parameters.csv wall_thickness (ASTM A1008 CR)
frame_depth_mm     = 90;    // parameters.csv frame_depth
rim_strip_width_mm = 12;    // parameters.csv rim_strip_width

/* [Head — parameters.csv] */
head_playing_od_mm = 430;   // parameters.csv head_playing_od
head_thickness_mm  = 0.5;   // ASSUMPTION: drum-head sheet ~0.5 mm (Skyndeep/goatskin)

/* [Tension screws — parameters.csv] */
tension_screw_qty  = 6;     // parameters.csv tension_screw_qty (60-deg spacing)
tension_screw_dia  = 4;     // parameters.csv tension_screw_size M4

/* [Tone bar — parameters.csv] */
tone_bar_length_mm    = 400; // parameters.csv tone_bar_length
tone_bar_width_mm     = 25;  // parameters.csv tone_bar_width
tone_bar_thickness_mm = 1.0; // parameters.csv tone_bar_thickness
mount_bracket_spacing = 300; // parameters.csv mount_bracket_spacing (c-c)
mount_bracket_l_mm    = 30;  // parameters.csv mount_bracket_blank_l

/* [Rosined wheel — parameters.csv] */
wheel_od_mm    = 50;   // parameters.csv rosined_wheel_od
wheel_width_mm = 8;    // parameters.csv rosined_wheel_width

/* [Render] */
$fn = 120;
show_head = true;

// Derived (formulas) -----------------------------------------------
frame_or = frame_od_mm / 2;
frame_ir = frame_or - wall_thickness_mm;   // parameters.csv frame_id/2 = 448/2
head_r   = head_playing_od_mm / 2;
screw_circle_r = frame_or - rim_strip_width_mm / 2;

// Rolled steel frame ring ------------------------------------------
module frame_ring() {
    difference() {
        cylinder(h = frame_depth_mm, r = frame_or);
        translate([0, 0, -1]) cylinder(h = frame_depth_mm + 2, r = frame_ir);
    }
}

// Rim bearing strip (top, inward flange) ---------------------------
module rim_strip() {
    translate([0, 0, frame_depth_mm - rim_strip_thickness()])
        difference() {
            cylinder(h = rim_strip_thickness(), r = frame_ir);
            translate([0, 0, -1])
                cylinder(h = rim_strip_thickness() + 2,
                         r = frame_ir - rim_strip_width_mm);
        }
}
function rim_strip_thickness() = wall_thickness_mm;  // rim_strip_thickness param

// Head disc (single playing surface) -------------------------------
module head() {
    translate([0, 0, frame_depth_mm])
        cylinder(h = head_thickness_mm, r = head_r);
}

// Tension screw field (M4 x qty, 60-deg spacing) -------------------
module tension_screws() {
    for (i = [0 : tension_screw_qty - 1])
        rotate([0, 0, i * 360 / tension_screw_qty])
            translate([screw_circle_r, 0, frame_depth_mm - 15])
                cylinder(h = 18, r = tension_screw_dia / 2);
}

// Internal tone bar on two mount brackets --------------------------
module tone_bar() {
    z = frame_depth_mm / 2;
    // bar
    translate([-tone_bar_length_mm/2, -tone_bar_width_mm/2, z])
        cube([tone_bar_length_mm, tone_bar_width_mm, tone_bar_thickness_mm]);
    // two mount brackets
    for (s = [-1, 1])
        translate([s * mount_bracket_spacing/2 - mount_bracket_l_mm/2,
                   -tone_bar_width_mm/2, 0])
            cube([mount_bracket_l_mm, tone_bar_width_mm, z]);
}

// Rosined wheel envelope (bowing wheel) ----------------------------
module rosined_wheel() {
    translate([head_r + wheel_od_mm/2 + 5, 0, frame_depth_mm/2])
        rotate([90, 0, 0])
            cylinder(h = wheel_width_mm, r = wheel_od_mm/2, center = true);
}

// Assembly ---------------------------------------------------------
module bowed_frame_drum() {
    color("SlateGray") frame_ring();
    color("Silver")    rim_strip();
    color("DimGray")   tension_screws();
    color("Goldenrod") tone_bar();
    color("DarkGoldenrod") rosined_wheel();
    if (show_head) color("Tan") head();
}

bowed_frame_drum();

echo(str("frame_or = ", frame_or, " mm; head_r = ", head_r,
         " mm; screws = ", tension_screw_qty, " x M", tension_screw_dia));

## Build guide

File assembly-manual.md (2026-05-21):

<!-- SPDX-License-Identifier: CC-BY-4.0 -->
# Assembly Manual — Bowed Frame Drum

## Overview

This manual covers final assembly after all parts are fabricated and finished. Assumes:
- Frame ring welded, rim strips welded, all drilled, finished
- Tone bar and mounts fabricated and deburred
- Wheel arm fabricated (if using bowing option)

## Tools for Assembly

- M4 hex key (3 mm)
- M3 hex key (2.5 mm)
- Rivet gun (for M3 blind rivets)
- Rubber mallet
- Tuner app (chromatic, microphone-based)
- Calipers

## Assembly Steps

### A. Mount Tone Bar Brackets

1. Locate two bracket positions inside frame: 180° apart at 45 mm depth.
2. Align bracket long leg flush against frame ID wall.
3. Mark and drill 2× ø3.3 mm rivet holes through bracket into frame using drill jig.
4. Drive 2× M3 × 6 mm blind rivets per bracket.
   *(Photo placeholder: bracket riveted to frame ID)*
5. Verify bracket short leg (grommet boss) points toward frame center.

### B. Install Tone Bar

6. Press neoprene grommet into bracket short leg boss (ø13.8 mm hole → ø14 mm grommet press-fit).
7. Slide tone bar (400 × 25 × 1 mm) through both grommet bores from one side.
8. Center bar: equal overhang (~0 mm) at each end inside frame.
9. Thread M3 × 20 mm cap-screw through tone bar end hole into frame (or just jam-nut against grommet).
   Finger-tight — let grommet provide isolation.
   *(Photo placeholder: tone bar suspended in grommets)*

### C. Install Rosined Wheel (Optional)

10. Insert wheel arm M5 bolt through frame top rim hole (12 o'clock position).
11. Place washer against frame OD, thread thumb-nut on bolt.
12. Install brass wheel on arm pivot (M5 × 12 mm bolt through arm, PTFE washer each side, nut).
13. Adjust thumb-nut: wheel arm should pivot under 100 g fingertip force.
14. Apply rosin to wheel: 3 strokes of cake rosin, warm surface with heat gun, repeat.
    *(Photo placeholder: wheel arm assembly detail)*

### D. Head Installation

15. Lay frame flat on clean workbench.
16. Place head (goatskin or synthetic, cut to ≥ 460 mm OD) over frame top edge.
17. Work evenly: press head down over rim all the way around with thumbs.
18. Place tension wrap-ring (430 mm OD) over head, seat against frame.
19. Insert 6× M4 × 30 mm cap screws into weld-nuts. Thread finger-tight.
20. Tighten in star pattern (1-4-2-5-3-6 order), 1/4 turn per pass.
21. Strike center of head with finger. Check pitch with tuner. Target: C3 (130.8 Hz).
22. Continue tightening in star pattern until fundamental is within ±15 Hz.
    *(Photo placeholder: tension ring installed, tuner app showing C3)*

### E. Sympathetic Ring Check

23. Strike head center firmly. Listen for secondary ring from tone bar (shimmer/sustain).
24. If tone bar ring is not audible, adjust bar mass:
    - Too high: add blu-tack or tape mass at center of bar (lowers pitch toward head overtone)
    - Too low: trim 5 mm from each end with angle grinder (raises pitch)
    *(Photo placeholder: close-up of tone bar with blu-tack adjustment)*

### F. Bowing Mode (Optional)

25. Engage wheel arm by pressing inward until wheel rim contacts head at inside edge.
26. Apply downward bow stroke along wheel OD while keeping head relatively still.
27. Sustained drone should emerge in the 80–260 Hz range depending on bow speed.
28. For cleaner drone: apply more rosin and bow at slower, consistent speed.

## Adjustment Reference

| Symptom | Cause | Fix |
|---|---|-----|
| Head fundamental too low | Insufficient tension | Tighten screws 1/4 turn star pattern |
| Head fundamental too high | Over-tensioned | Loosen evenly |
| Tone bar does not ring | Pitch mismatch | Add/remove mass on bar |
| Tone bar chatters audibly | Grommet loose | Replace grommet or add thin foam backing |
| Wheel squeaks but no sustain | Insufficient rosin | Apply more rosin |
| Wheel squeaks and head muffles | Wheel pressing too hard | Back off thumb-nut |

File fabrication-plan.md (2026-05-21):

<!-- SPDX-License-Identifier: CC-BY-4.0 -->
# Fabrication Plan — Bowed Frame Drum

## Tools Required (Maker Nexus)

- Slip roll (≥ 90 mm width capacity, adjustable to 450 mm OD)
- TIG welder with 1/16" (1.6 mm) ER70S-6 filler
- MIG welder (tack only)
- Angle grinder + flap disc 80-grit, 120-grit
- Press brake or bench brake (≥ 90° capacity, 25 mm length)
- Bench drill press, M4 and M5 bits
- Plasma or fiber laser cutter (for tone bar and brackets)
- Bench vise, V-block jig for cylindrical parts
- Roto-cutter / deburring tool
- Rubber mallet

## Step-by-Step Sequence

### Stage 1 — Frame Ring (slip-roll + TIG)

**Materials**: 1.0 mm CR steel sheet, 1500 mm × 115 mm stock panel

1. **Shear blank** to 1414.7 mm × 90.0 mm on power shear. Mark seam end with center-punch.
2. **Slip-roll coupon first** — roll a 200 × 90 mm test piece, measure spring-back OD,
   adjust roll gap. Target: OD = 450 mm ± 1 mm after spring-back.
3. **Roll frame blank** into cylinder. Lead the blank in square to rolls.
4. **Check roundness** with calipers at 4 positions. Adjust roll as needed.
5. **Tack-weld seam**: clamp in V-block, 4 tack welds evenly spaced along 90 mm seam.
6. **TIG butt-weld**: continuous weld from inside face, full penetration.
   Heat input: ~60 A, 14 V; travel speed ~5 mm/s. Let cool without quenching.
7. **Flap-disc**: grind seam flush on both ID and OD. 80-grit then 120-grit.
8. **Recheck roundness**: out-of-round < 1 mm.
9. **Drill tension holes**: 6× ø4.5 mm holes at 60° spacing on OD, centered at 45 mm depth.
   Use drill press + sine plate fixture to hit correct angular positions.
10. **Tap holes or install weld-nuts**: M4 weld-nuts TIG-tacked to frame OD at each hole.

### Stage 2 — Rim Reinforcement Strips

**Materials**: 1.0 mm CR steel, 2× strips 1414.7 mm × 12 mm

11. **Shear 2× rim strips** to 1414.7 mm × 12.0 mm.
12. **Roll each strip** alongside frame cylinder using same roll gap.
    Tip: roll simultaneously with frame if machine has multi-bead guides.
13. **Seat strips** against frame top and bottom edges, flush.
14. **MIG tack** at 6 positions per strip, evenly spaced.
15. **TIG continuous weld** both edges of each strip — inside and outside corners.
    Total weld length: 4 × 1414.7 mm ≈ 5658 mm (do in segments, cool between passes).

### Stage 3 — Tone Bar, Brackets, Wheel Arm (bench metal / laser)

**Materials**: 1.0 mm CR steel sheet, laser or plasma cut from nested layout

16. **Laser/plasma cut**: tone bar (400 × 25 mm + 2× grommet holes),
    2× mount brackets (30 × 25 mm + holes), wheel arm (80 × 15 mm + pivot hole).
17. **Deburr all parts** with roto-cutter and fine-grit stone. All edges: 0.2 mm chamfer minimum.
18. **Brake-form mount brackets**: 90° bend at 15 mm on press brake. Confirm 90° ± 0.5°.
19. **Brake-form wheel arm**: first 45° bend at 20 mm, then 45° return at 50 mm.
    Sequence: clamp long end, bend near end first; flip, second bend.
20. **Install grommets**: press ø14 mm neoprene grommets into ø13.8 mm holes in bracket short legs.
    Light press-fit; do not damage grommet bore.

### Stage 4 — Internal Assembly

21. **Mark bracket positions** on frame ID: 180° apart, 45 mm from either end.
22. **Rivet brackets**: 2× M3 × 6 mm blind rivets through bracket long leg into frame.
    Verify bracket short leg (grommet) faces frame interior center.
23. **Thread tone bar** through both grommets. Secure with M3 × 20 mm cap-screw + jam-nut
    at each end, finger-tight only — grommet grip provides damping.
24. **Tone bar alignment**: center bar at 45 mm depth, parallel to frame faces.

### Stage 5 — Rosined Wheel Option

25. **Drill M5 pivot hole** through frame top rim at 12 o'clock position.
26. **Install wheel arm**: M5 × 30 mm bolt through frame hole, arm between frame and large washer.
    Thumb-nut allows tension adjustment.
27. **Mount brass wheel** on M5 × 12 mm pivot bolt through arm, with needle bearing or PTFE washer.
28. **Apply rosin**: 3× passes of cake rosin on wheel edge. Warm wheel with heat gun for first coat.

### Stage 6 — Finish

29. **Sand entire frame**: 120 → 220 → 320 grit by hand. Remove all scratches, weld spatter.
30. **Finish options** (choose one):
    - Matte black rattle-can (rust-oleum self-etching primer + matte black topcoat)
    - Natural steel + paste wax (bare metal aesthetic)
    - Powder coat (off-site)
31. **Let finish cure** 24 hrs before head installation.

### Stage 7 — Head Installation

32. **Source head**: Remo Skyndeep 18" (457 mm) or cut goatskin to 460 mm OD.
33. **Wet goatskin** (if natural): soak 10 min, pat dry, stretch over frame immediately.
34. **Seat head**: drape over frame top edge, pull evenly around circumference.
35. **Install tension ring**: 430 mm OD aluminum or steel wrap-ring pressed over head and frame edge.
36. **Install 6× M4 × 30 mm cap screws** with 6× M4 weld-nuts on OD. Tighten in star pattern.
37. **Let dry / stabilize**: natural skin — 2 hrs; synthetic — 15 min.
38. **Final tune**: strike center, measure with tuner app. Target C3 (130.8 Hz).
    Tighten screws 1/4 turn at a time in star pattern until fundamental is reached.

## Inspection Gates

| Gate | Criterion | Tool |
|---|---|---|
| After step 8 | Frame OD 450 ± 1 mm, out-of-round < 1 mm | Calipers |
| After step 15 | Rim strips flush, no gaps > 0.5 mm | Feeler gauge |
| After step 23 | Tone bar floats freely in grommets | Manual tap |
| After step 38 | Head fundamental 130 ± 15 Hz | Tuner app |
| Sympathetic ring | Tone bar audible ring after head strike | Listen, stethoscope |

## Safety Notes

- TIG on 1.0 mm sheet: low heat input to prevent burn-through. Practice on coupon.
- Slip-roll nip hazard: never feed fingers close to the rollers.
- Grinder sparks: clear flammables, use face shield.
- Rosin: flammable dust — keep heat gun away from loose rosin.

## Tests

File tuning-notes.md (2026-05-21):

<!-- SPDX-License-Identifier: CC-BY-4.0 -->
# Tuning Notes — Bowed Frame Drum

## Head Tuning

### Physics

The fundamental frequency of a circular membrane under uniform tension:

```
f₀₁ = (2.4048 / (2π r)) × √(T / σ)

where:
  r  = head radius = 0.215 m (430 mm / 2)
  T  = surface tension in N/m
  σ  = surface mass density in kg/m² (goatskin ≈ 0.35; Remo Skyndeep ≈ 0.25)
  2.4048 = first zero of Bessel function J₀
```

### Screw-Torque-to-Pitch Mapping

Each M4 × 30 mm cap screw applies ~100 N/mm torque conversion to head tension
(approximate; depends on head material and wrap geometry).

| Turns tightened | ΔT (N/m est.) | Δf₀₁ (Hz est.) |
|---|---|---|
| 1/4 turn | +12 N/m | +4–8 Hz |
| 1/2 turn | +24 N/m | +8–15 Hz |
| 1 full turn | +48 N/m | +15–30 Hz |

Always tighten in **star pattern** (positions 1-4-2-5-3-6) to maintain even tension.

### Target: C3 (130.8 Hz)

Strike center of head with finger; use chromatic tuner app. If fundamental is:
- **Below 115 Hz**: tighten all 6 screws 1 full turn star pattern; recheck
- **115–125 Hz**: tighten 1/2 turn star pattern
- **125–135 Hz**: tighten 1/4 turn at a time
- **Above 145 Hz**: loosen 1/4 turn star pattern

### Goatskin Humidity Sensitivity

Natural skin heads detune with humidity changes (pitch drops in high humidity).
Retune before each playing session. Store drum in stable humidity environment (40–60% RH).
Synthetic (Remo Skyndeep) is humidity-stable — tune once, check monthly.

## Tone Bar Tuning

### Target: C4 (261.6 Hz), mode 1 bending

The tone bar bending fundamental is set by its length:

```
f_bar1 = (22.3733 / (2π L²)) × √(E I / (ρ A))

where:
  L = bar length (m)
  I = b h³ / 12  (b=0.025m width, h=0.001m thickness)
  A = b × h
  E = 200 GPa, ρ = 7850 kg/m³
```

At L = 400 mm: f_bar1 ≈ 257 Hz (~C4 - 27 cents)

### Trimming Procedure

| Trim from each end | New f_bar1 (approx) |
|---|---|
| 0 mm (full 400 mm) | 257 Hz |
| 5 mm → 390 mm | 270 Hz |
| 10 mm → 380 mm | 285 Hz |
| 20 mm → 360 mm | 318 Hz |

Trim with angle grinder, 1 mm at a time from each end equally. Tap bar and measure
frequency with tuner app after each trim. Deburr cut end before reinstalling.

### Mass-Loading (No-Cut Adjustment)

Attach small pieces of blu-tack or putty at the center of the bar to lower pitch:
- ~1 gram at center → lowers f_bar1 by ~5–10 Hz
- Remove mass by peeling off

This is the safest first adjustment before committing to length trimming.

## Rosined Wheel Bowing

### Slip-Stick Mechanics

The wheel produces sustained sound via stick-slip oscillation where:
1. Wheel **sticks** to head surface due to rosin friction
2. Head membrane deflects until restoring force exceeds static friction
3. Wheel **slips** suddenly, membrane springs back
4. Cycle repeats at the head's natural resonant frequency

The acoustic output frequency is set by the **membrane resonance**, not the wheel rotation rate.
The wheel simply provides continuous excitation energy.

### Optimal Bowing Parameters

| Parameter | Optimum |
|---|---|
| Wheel contact pressure | Light (50–100 g equivalent) |
| Bow speed (rim speed) | 0.2–0.5 m/s |
| Rosin freshness | Apply before each session |
| Head humidity | Dry is better (skin grips rosin better) |

### Drone Modes Available

- **Head fundamental (C3, 130 Hz)**: engage wheel with gentle pressure, slow bow
- **Head overtone (A3, 220 Hz)**: increase pressure + slightly faster bow; excites f₁₁ mode
- **Continuous sweep**: vary bow speed mid-stroke — pitch shifts as different modes lock

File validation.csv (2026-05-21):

# SPDX-License-Identifier: CERN-OHL-W-2.0
target_metric | predicted | measured | units | pass_fail | tolerance | notes
head_fundamental_hz | 130.0 |  | Hz | pending | ±15 Hz | C3 = 130.81 Hz; Bessel mode f01 with T_head derived from target
head_overtone_f11_hz | 219.3 |  | Hz | pending | ±20 Hz | Bessel mode f11; ratio f11/f01 = alpha_11/alpha_01 = 1.593
tone_bar_mode1_hz | 257.4 |  | Hz | pending | ±13 Hz | Euler-Bernoulli free-free mode 1 for 400x25x1mm bar (~C4)
tone_bar_mode2_hz | 709.8 |  | Hz | pending | informational | free-free mode 2; not targeted for sympathetic coupling
sympathetic_coupling_head_f11_vs_bar_mode1_pct | 17.4 |  | pct | pending | <25% audible | f_bar1=257.4 vs head f11=219.3; delta=17.4%; audible but not locked
head_surface_tension_N_per_m | 194.9 |  | N/m | pending | informational | derived from T_head solve for f01=130Hz given sigma=0.35 kg/m2
frame_out_of_round_mm |  |  | mm | pending | <1.0 mm | measured at 4 points 90 deg apart with calipers after welding
rim_strip_flush_mm |  |  | mm | pending | <0.5 mm gap | feeler gauge check after welding
head_hold_under_playing_force |  |  | pass/fail | pending | head stays seated | qualitative: no head detachment after 30 min playing test
tone_bar_sympathetic_ring |  |  | pass/fail | pending | audible at 1m | subjective: strike head center; listen for shimmer ring from bar
bowing_drone_sustain_sec |  |  | seconds | pending | >3s | minimum sustained drone duration with consistent bow speed
total_mass_kg | 0.91 |  | kg | pending | <1.5 kg | estimated: frame 700g + head 80g + hardware 130g
ergonomic_grip_depth_mm | 90 |  | mm | pending | 80-110 mm | frame depth sets grip; measured at frame edge

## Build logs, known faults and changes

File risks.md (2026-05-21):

<!-- SPDX-License-Identifier: CC-BY-4.0 -->
# Risks — Bowed Frame Drum

## Safety Risks

| Risk | Severity | Mitigation |
|---|---|---|
| TIG burn-through on 1.0 mm sheet | Medium | Run coupon first; 60 A max; keep travel speed consistent; V-block fixture to prevent warping |
| Slip-roll nip point | High | Never feed fingers past roll nip; stop roll before removing workpiece |
| Grinder sparks near rosin | Medium | Keep rosin in closed container during grinding; clear flammables |
| Sharp edges on deburred parts | Low | Full deburr protocol (roto-cutter + stone); wear gloves during handling |

## Manufacturability Risks

| Risk | Likelihood | Impact | Mitigation |
|---|---|---|---|
| Spring-back causes out-of-round frame | Medium | High | Mandatory coupon test before rolling full frame; adjust roll gap |
| TIG seam distorts frame from heat | Medium | Medium | Clamp in V-block jig; weld in short passes; allow cool-down between passes |
| Rim strip weld creates high spot on bearing edge | Low | High | Grind and check with straightedge; re-weld if needed |
| Wheel arm angle incorrect — wheel misses head | Medium | Medium | Prototype wheel arm in card stock first; verify geometry before cutting steel |
| Grommet press-fit too tight — damages grommet | Low | Low | Test grommet OD/hole diameter on scrap bracket before riveting to frame |

## Acoustic Risks

| Risk | Likelihood | Impact | Mitigation |
|---|---|---|---|
| Head fundamental too low to reach with available tension | Low | High | Tune first without tone bar; if tension maxed at <100 Hz, head is too slack (replace with thinner synthetic head) |
| Tone bar coupling inaudible | Medium | Low | Coupling delta is 17.4% — audible but not locked. Shorten bar by 20 mm to raise f_bar to 280 Hz (closer to head overtone) |
| Rosined wheel produces only squeak, not sustained tone | Medium | Medium | Increase rosin thickness; reduce wheel contact pressure; experiment with slower bow speed |
| Frame resonance interferes with head tone | Low | Medium | Steel frame is ~20× stiffer than goatskin; frame breathing modes are above 500 Hz — unlikely to conflict |
| Sympathetic bar creates undesirable rattle | Low | Low | Grommet isolation prevents rattle; if rattle appears, add thin foam strip between bar and grommet |

## Ergonomic Risks

| Risk | Impact | Mitigation |
|---|---|---|
| Frame too heavy for extended playing | Low | Mass budget ~900 g; lighter than many wood frames (900–1200 g for laminate). |
| Wheel arm scratches player's arm | Low | Bevel wheel arm tail; file all exposed corners |
| Tension screws back out during playing | Low | Apply threadlocker (Loctite 222) to all M4 tension screws after final tune |

## GitHub / Publishing Risk

- If `gh repo create` fails in sandbox environment: document in this file, proceed with local
  commits, and manager will push from WSL host.
- Status: `gh repo create` succeeded — no issue.

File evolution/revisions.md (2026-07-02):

# Revision Register — bowed-frame-drum

| Rev | Date | Parent | Delta | Downstream artifacts invalidated |
| --- | --- | --- | --- | --- |
| A | 2026-07-01 | — | Stage 0 intake of current masters (cad/bowed-frame-drum.scad envelope + parameters.csv). | none (no alpha/beta/production artifacts exist yet) |

Stage 0 only. Gate A has not been run; no Alpha compiles, vendor quotes, or production lock exist for this product.

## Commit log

2026-05-21 feat: parametric design.md parameters.csv wolfram-starter.wl (#1)
    [parameters.csv]
2026-05-21 feat: solidworks plan flat-pattern checklist bend-table cut-list directories (#2)
    [bend-table.csv, cut-list.csv]
2026-05-21 feat: fabrication plan assembly manual BOM sourcing hardware supplier-rfq (#3)
    [bom.csv, hardware.csv, sourcing.csv]
2026-05-21 feat: validation predictions risks tuning-notes photo-shotlist visual-bom-brief (#4)
    [validation.csv]
2026-05-30 v5-migrate(bowed-frame-drum): register + mcp-log + status (Refs instrument-maker#184) (#6)
    [visual-output-register.csv]
2026-05-30 chore(bowed-frame-drum): add .gitignore (Refs instrument-maker#195) (#7)
2026-05-31 wolfram-rename(bowed-frame-drum): unique {slug}-starter.wl + dedupe + ref fixes (cloud-sync naming) (#8)
    [visual-output-register.csv]
2026-05-31 docs(bowed-frame-drum): add image-gen prompt (#9)
2026-05-31 Add image-gen concept prompt; wire explorer images
2026-05-31 Add deployable Wolfram interactive model + wire live explorer embed
    Model returns a bare Manipulate (SaveDefinitions->True); CloudDeploy'd Public.
2026-06-23 feat(wolfram): deploy interactive model + live explorer embed (#11)
    * feat(v5): upgrade explorer to V5 format + fill build-packet gaps
    - Replace explorer.html with V5 parchment card format: readiness chip,
    authority-split chip, family chip, per-artifact authority badges
    (fabrication / derived_preview / reference_only / source_only)
    - Add data/deliverables-export.json machine-readable manifest
    - Add any missing build-packet stubs (drawing-brief.md, assembly-manual.md,
    supplier-rfq.md, visual-bom-brief.md, photo-shotlist.md, sourcing.csv,
    cut-list.csv, cnc/setup-sheet.md) as TBD-ready placeholders
    Refs instrument-maker v4.5 · tonykoop/bowed-frame-drum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
2026-07-02 V5 packet refresh: status line, provenance, parametric OpenSCAD master, evolution intake
    - Author cad/bowed-frame-drum.scad parametric frame-drum envelope master
    (frame ring + head + rim strip + 6xM4 tension field + internal tone bar on
    brackets + rosined wheel; all dims from parameters.csv; tuning-sensitive tone-
    bar/wheel/tension out of scope). openscad render check: pass (Simple: yes, exit 0).
    - Register rows for .scad (pending_measurement) and wolfram/ model (derived_preview);
    provenance row added to cad/mcp-session-log.md.
    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
    [bowed-frame-drum.scad, visual-output-register.csv]
